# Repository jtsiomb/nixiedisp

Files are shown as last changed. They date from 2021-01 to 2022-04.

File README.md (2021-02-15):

nixiedisp - USB nixie tube display
==================================

nixiedisp

Nixiedisp is a 6-digit nixie tube numeric display, software-controlled over USB
or RS232, that also functions standalone as a clock.

Features:
  - Controlled over USB or RS232 serial port to display arbitrary numbers, set
    the time/date, change settings, and switch between modes of operation.
  - Standalone operation as a clock or stopwatch timer with a battery-backed
    real-time clock (CR2032 coin cell).
  - Designed to use soviet IN-14 nixie tubes.
  - Powered by a 12v DC supply through a standard 2mm barrel jack (center-positive).

Excercise caution when operating without an enclosure, there are high voltages
(180V DC) present in the power supply section of the board, and around the
nixie tubes.

Project website: http://nuclear.mutantstargoat.com/hw/nixiedisp  
Github repo: https://github.com/jtsiomb/nixiedisp  

Project structure:

 - `hw/`: hardware design
 - `fw/`: firmware for the on-board AVR microcontroller
 - `sw/`: end-user host-side software for controlling the device from a computer

License
-------
Copyright (C) 2020-2021 John Tsiombikas <nuclear@member.fsf.org>

Hardware designs and software (firmware) in this project are free. Feel free to
use, modify, and/or redistribute under the terms of the GNU General Public
License v3, or at your option any later version published by the Free Software
Foundation. See COPYING for details.

How to build a nixiedisp device
-------------------------------
To build one of these for yourself, you need to:

  1. Zip up the contents of the `hw/gerber` directory, and send them to a PCB
     manufacturer to get boards made. For my own boards I used `jlcpcb.com`.

  2. Order the components listed in the bill of materials (`hw/bom.ods`). I
     ordered mine from `mouser.com`, and the spreadsheet contains the mouser
     reference number for each component, to make it easy to order the whole lot
     without too much searching. Make sure to order at least as many of each one
     of them, as specified in the bom.

  3. Find 6 (optionally 4) soviet IN-14 nixie tubes. They tend to go for about
     $10 - $15 each on ebay.

  4. Find a 12v DC power supply with a barrel jack (2mm center pin),
     center-positive (`+ -o)- -`), to power the board. It doesn't have to be
     regulated, but it must be able to provide about 500mA at 12v.
     Typical power consumption is 2-3W.

  5. If you got the git version of this project, you'll need to build the
     firmware by changing into `fw` and typing `make`. You'll need to have
     `avr-gcc`, `libc-avr`, and GNU make installed for this. Release archives
     include a pre-built firmware image you can use (`fw/nixiedisp.hex`).

  6. Assemble the board, and program the microcontroller with a suitable AVR
     ISP. If you have `avrdude` installed, you can simply change into `fw` and
     type `make program`, with the board powered up and the programmer
     connected.

If you don't need the serial port (RS232) option, you can leave J1 (the DB9
connector), U2 (max232 level converter) and all its surrounding electrolytic
capacitors (C1, C2, C4, C8 and C15) unpopulated, and install a 10k pull-up
resistor across the pads of J7 (usbpwr).

References
----------
High-voltage power supply based on Michael Moorrees' nixie supply MK1.5:
https://threeneurons.wordpress.com/nixie-power-supply

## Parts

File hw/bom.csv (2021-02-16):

Reference | Quantity | Description | Footprint | Mouser ID | Unit price | Cost
BT1 | 1 | CR2032 battery holder | SMD battery holder Keystone 1060 | 534-1060TR | 1.380 € | 1.380 €
C3 C5 C6 C7 C9 C10 C13 C14 C17 C18 C21 C24 C27 C30 C33 | 15 | 0.1uF | SMD 0805 | 581-08055C104K | 0.034 € | 0.510 €
C11 C12 | 2 | 22pF | SMD 0805 | 80-C0805C220K1HACTU | 0.032 € | 0.064 €
C16 | 1 | 2.2nF | SMD 0805 | 187-CL21B222JBANNNC | 0.020 € | 0.020 €
C1 C2 C4 C8 C15 | 5 | 1uF electrolytic (RS232 option) | SMD electrolytic 4x5.4 | 710-865060640001 | 0.136 € | 0.680 €
C35 C36 | 2 | 0.33uF electrolytic | SMD electrolytic 4x5.4 | 710-865230640003 | 0.152 € | 0.304 €
C37 | 1 | 220uF low-ESR electrolytic | SMD electrolytic 8x10 | 667-EEE-FP1V221AL | 0.526 € | 0.526 €
C38 | 1 | 10nF | SMD 0805 | 187-CL21B103JBANNNC | 0.020 € | 0.020 €
C39 | 1 | 2.2uF 250V | Through-hole radial electrolytic | 647-UVR2E2R2MED1TD | 0.220 € | 0.220 €
D1 | 1 | 1N4148 | SMD SOD-323 (0805) | 750-1N4148WS-HF | 0.106 € | 0.106 €
D2 | 1 | MUR160 | SMD DO-214A (SMB) | 821-MUR160SR5G | 0.250 € | 0.250 €
J1 | 1 | DB9 male (RS232 option) | Through-hole DB9 male | 523-L717SDE09P1ACH | 1.350 € | 1.350 €
J2 | 1 | Micro-USB connector | USB Micro-B Molex-105017-0001 | 538-105017-0001 | 0.703 € | 0.703 €
J3 | 1 | AVR programming header | 2x3 male pin header 2.54mm pitch | 710-61200621621 | 0.381 € | 0.381 €
J4 | 1 | DC barrel jack | barrel jack 2mm center pin | 490-PJ-202A | 0.500 € | 0.500 €
J5 | 1 | Hour-separator LED connector | 1x3 female socket 2.54mm pitch | 538-90147-1103 | 0.930 € | 0.930 €
J6 | 1 | pwr sw | 1x2 male pin header 2.54mm pitch | 538-22-28-4112 | 0.398 € | 0.398 €
L1 | 1 | 220uH | SMD inductor 14x18.3 | 652-SDR1806-221KL | 0.813 € | 0.813 €
Q1 Q2 | 2 | MMBTA55 PNP transistor | SMD SOT-23 | 863-MMBTA55LT1G | 0.152 € | 0.304 €
Q3-Q68 | 66 | MMBTA42 NPN transistor | SMD SOT-23 | 863-MMBTA42LT1G | 0.054 € | 3.564 €
Q69 | 1 | IRF740A | SMD TO-263-3 | 844-IRF740ASPBF | 1.700 € | 1.700 €
R1 R2 R27 | 4 | 10k | SMD 0805 | 71-CRCW080510K0JNEAC | 0.033 € | 0.132 €
R15-R20 R22-R26 R28-R33 R35-R39 R41-R46 R48-R52 R54-R59 R61-R65 R67-R72 R74-R78 R80-R85 R87-R91 | 66 | 47k | SMD 0805 | 652-CR0805FX-4702ELF | 0.007 € | 0.462 €
R21 R34 R47 R60 R73 R86 | 6 | 160k | SMD 0805 | 660-RK73H2ATTD1603F | 0.013 € | 0.078 €
R3 R4 R7 | 3 | 1 ohm | SMD 0805 | 603-RC0805FR-071RL | 0.044 € | 0.132 €
R5 R6 R8 | 2 | 1k | SMD 0805 | 71-CRCW08051K00JNEAC | 0.033 € | 0.066 €
R9 R10 R11 R12 R13 R14 | 6 | 24k | SMD 0805 | 660-RK73H2ATTD2402F | 0.014 € | 0.084 €
R93 | 1 | 475k | SMD 0805 | 667-ERJ-6ENF4753V | 0.055 € | 0.055 €
R94 | 1 | 3.32k | SMD 0805 | 71-CRCW0805-3.32K-E3 | 0.048 € | 0.048 €
SW1-SW3 | 1 | Right-angle tactile button | SMD right-angle | 113-TA34W2VTR | 1.360 € | 1.360 €
U1 | 1 | Atmega328PB-AU | TQFP-32 | 556-ATMEGA328PB-AU | 1.130 € | 1.130 €
U14 U15 U16 U17 U18 U19 | 6 | 74HC4514 | SOIC-24 wide | 771-74HC4514D-T | 0.864 € | 5.184 €
U2 | 1 | MAX232 (RS232 option) | SOIC-16 | 595-MAX232DR | 0.737 € | 0.737 €
U3 | 1 | 74HC126 | SOIC-14 | 595-SN74HC126DR | 0.237 € | 0.237 €
U32 | 1 | DS1302Z+ | SOIC-8 | 700-DS1302ZT&R | 2.790 € | 2.790 €
U33 | 1 | MC34063AD | SOIC-8 | 595-MC34063ADR | 0.296 € | 0.296 €
U34 | 1 | 7805 | SMD TO-252-2 DPAK | 863-MC7805CDTRKG | 0.356 € | 0.356 €
U4 | 1 | MCP2221AxSL | SOIC-14 | 579-MCP2221A-I/SL | 1.680 € | 1.680 €
U5 U6 U7 | 3 | 74HC164 | SOIC-14 | 771-74HC164D-T | 0.220 € | 0.660 €
U8 U9 U10 U11 U12 U13 | 6 | IN14 | Nixie tube IN-14 |  |  | 0.000 €
Y1 | 1 | 14.7456MHz | SMD crystal ECS CSM3X 2pin 7.6x4.1mm | 815-ABLS7M-14.745B2T | 0.288 € | 0.288 €
Y2 | 1 | 32.768KHz | SMD crystal 2-pin 2x1.2mm (alt.footprint Y3) | 815-ABS0632768KHZ61T |  | 0.000 €
Y3 | 1 | 32.768KHz | Through-hole crystal 3x8mm (alt.footprint Y2) | 695-CFS-20632768EZBB | 0.347 € | 0.347 €
 | 2 | Amber 3mm LED (hour sep.) | Through-hole 3mm LED | 859-LTL-1CHA | 0.144 € | 0.288 €
 |  |  |  |  | Total cost: | 31.133 €

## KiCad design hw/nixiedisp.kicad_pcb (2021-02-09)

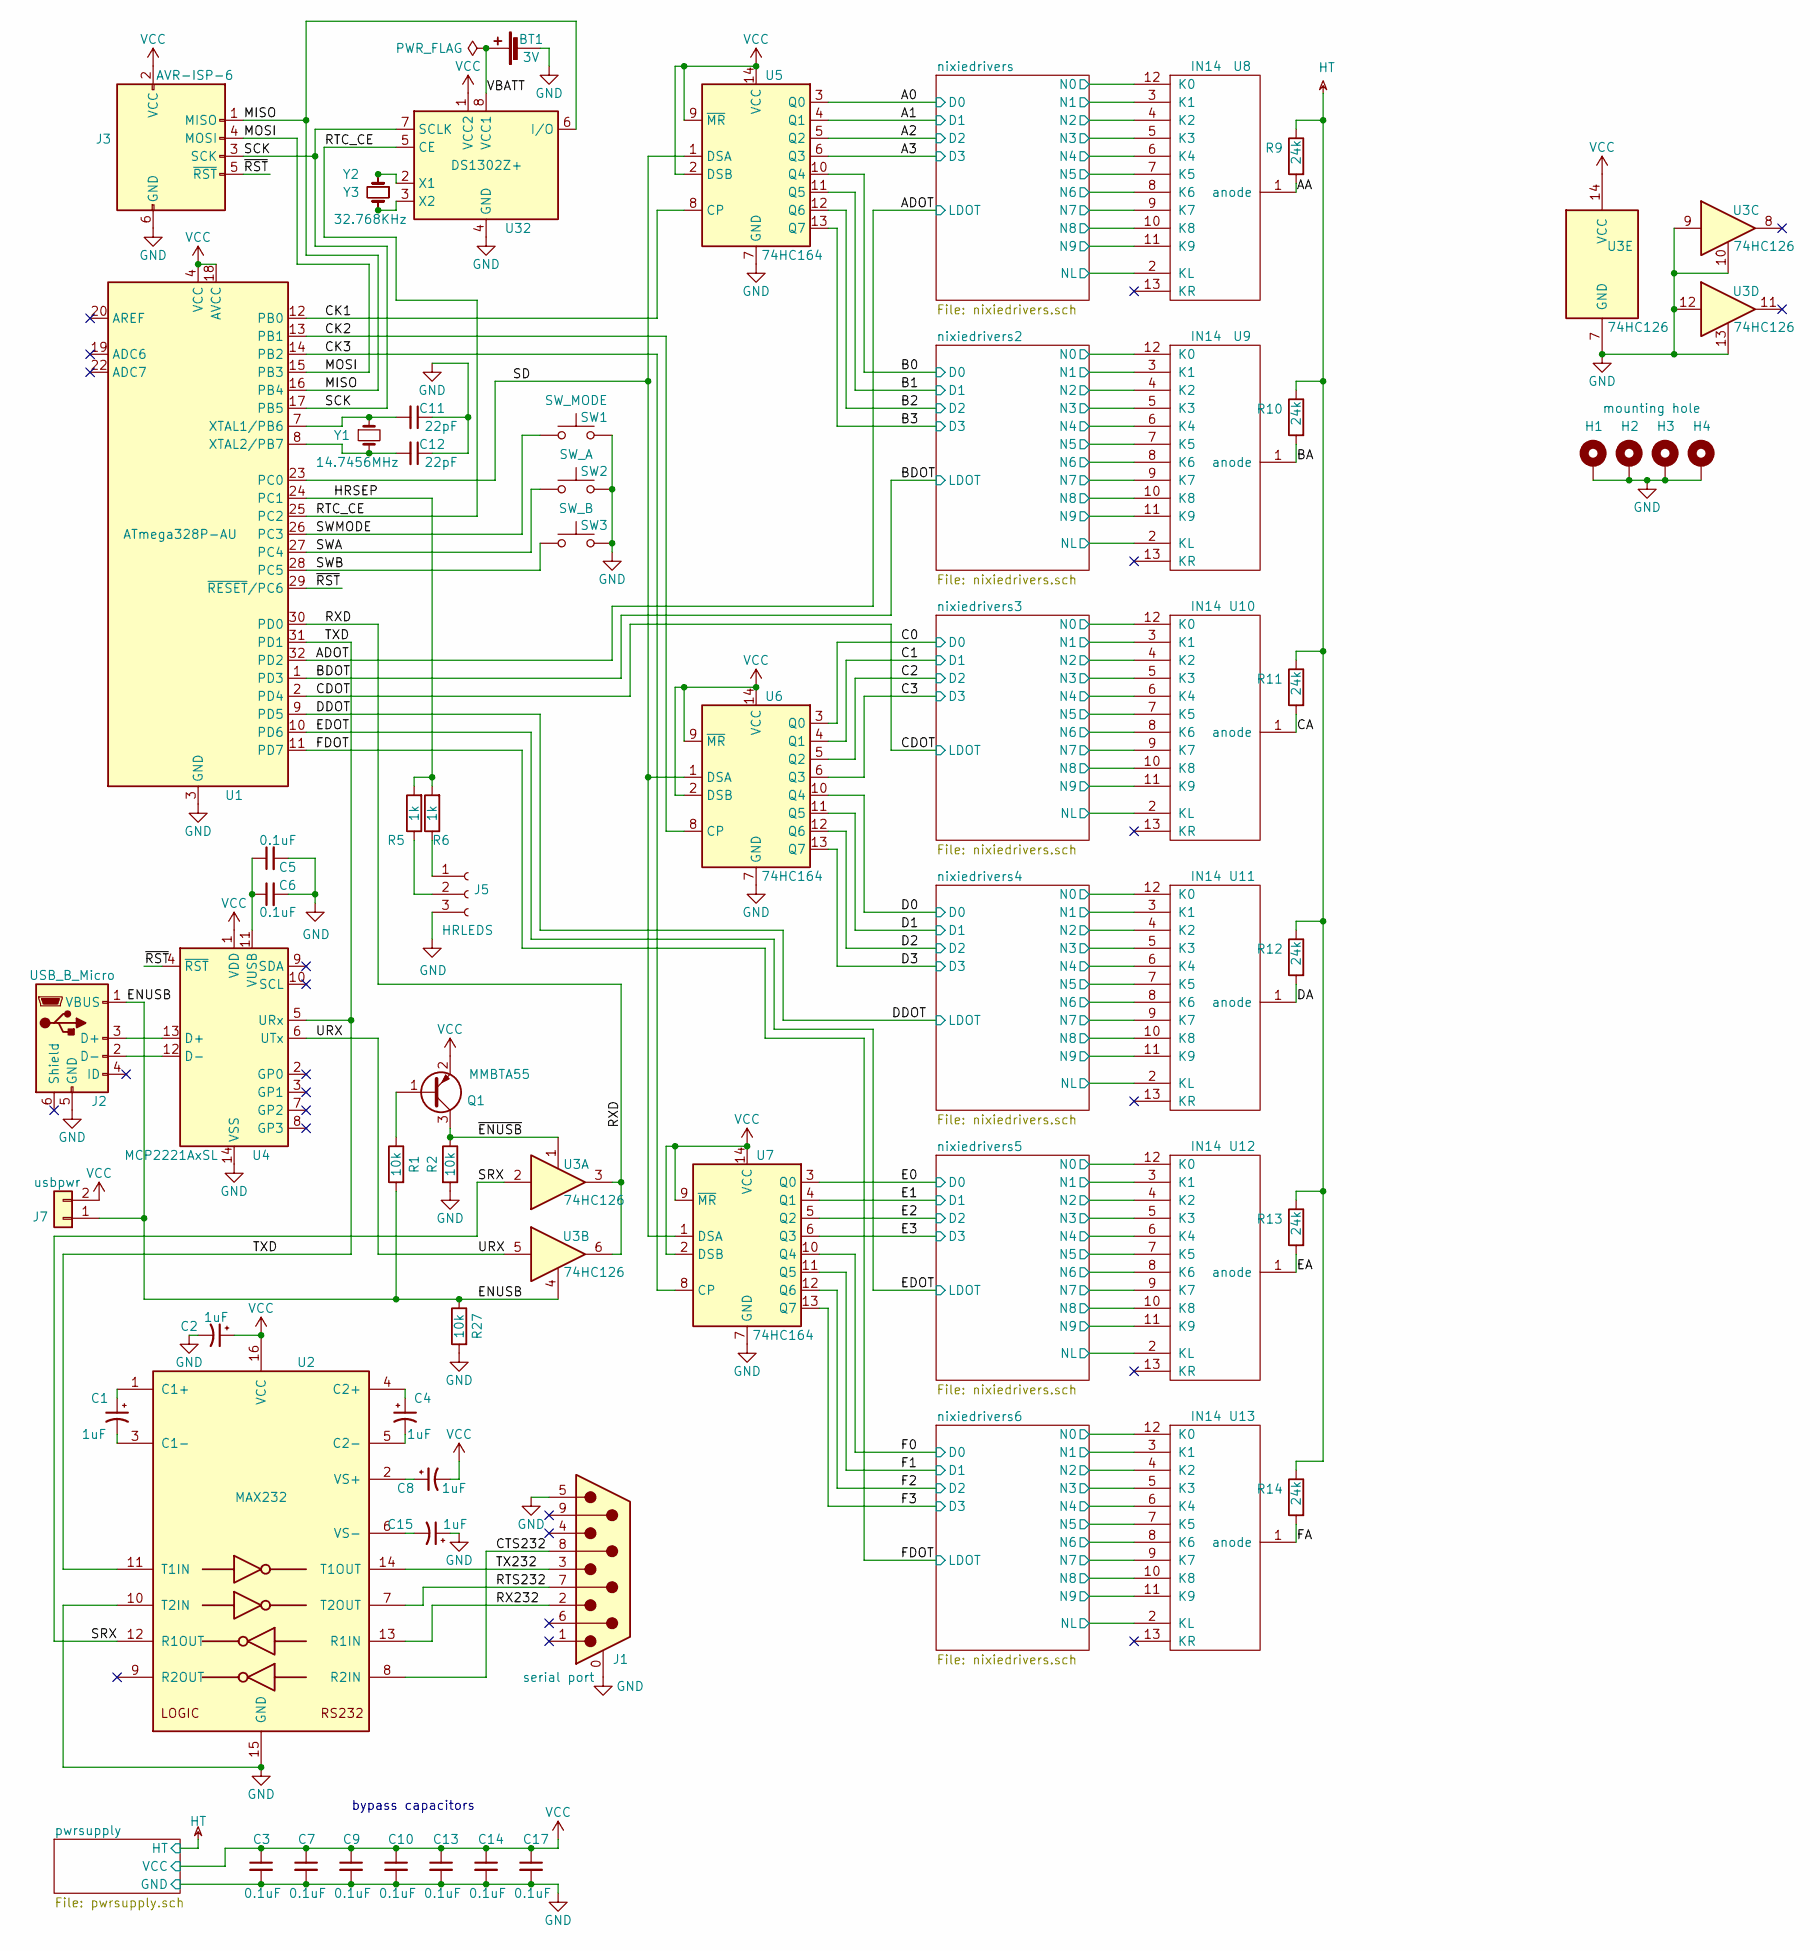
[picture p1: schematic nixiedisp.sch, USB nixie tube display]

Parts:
BT1: 3V; BatteryHolder_Keystone_1060_1x2032
C1, C2, C4, C8, C15: 1uF; CP_Elec_4x3.9
C3, C5, C6, C7, C9, C10, C13, C14, C17: 0.1uF; C_0805_2012Metric_Pad1.15x1.40mm_HandSolder
C11, C12: 22pF; C_0805_2012Metric_Pad1.15x1.40mm_HandSolder
H1, H2, H3, H4: mounting hole; MountingHole_3.2mm_M3_Pad_Via
J1: serial port; DSUB-9_Male_Horizontal_P2.77x2.84mm_EdgePinOffset7.70mm_Hou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
J2: USB_B_Micro; USB_Micro-B_Molex-105017-0001
J3: AVR-ISP-6; IDC-Header_2x03_P2.54mm_Vertical
J5: HRLEDS; PinSocket_1x03_P2.54mm_Vertical
J7: usbpwr; PinHeader_1x02_P2.54mm_Vertical
Q1: MMBTA55; SOT-23
R1, R2, R27: 10k; R_0805_2012Metric_Pad1.15x1.40mm_HandSolder
R5, R6: 1k; R_0805_2012Metric_Pad1.15x1.40mm_HandSolder
R9, R10, R11, R12, R13, R14: 24k; R_0805_2012Metric_Pad1.15x1.40mm_HandSolder
SW1: SW_MODE; switch
SW2: SW_A; switch
SW3: SW_B; switch
U1: ATmega328P-AU; TQFP-32_7x7mm_P0.8mm
U2: MAX232; SOIC-16_3.9x9.9mm_P1.27mm
U3: 74HC126; SOIC-14_3.9x8.7mm_P1.27mm
U4: MCP2221AxSL; SOIC-14_3.9x8.7mm_P1.27mm
U5, U6, U7: 74HC164; SOIC-14_3.9x8.7mm_P1.27mm
U8, U9, U10, U11, U12, U13: IN14; nixie_in14
U32: DS1302Z+; SOIC-8_3.9x4.9mm_P1.27mm
Y1: 14.7456MHz; Crystal_SMD_ECS_CSM3X-2Pin_7.6x4.1mm
Y2: 32.768KHz; Crystal_SMD_2012-2Pin_2.0x1.2mm_HandSoldering
Y3: 32.768KHz; Crystal_C38-LF_D3.0mm_L8.0mm_Horizontal

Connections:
/A0: U5.3 (Q0); also elsewhere on the board
/A1: U5.4 (Q1); also elsewhere on the board
/A2: U5.5 (Q2); also elsewhere on the board
/A3: U5.6 (Q3); also elsewhere on the board
/AA: R9.2, U8.1 (anode)
/ADOT: U1.32 (PD2); also elsewhere on the board
/B0: U5.10 (Q4); also elsewhere on the board
/B1: U5.11 (Q5); also elsewhere on the board
/B2: U5.12 (Q6); also elsewhere on the board
/B3: U5.13 (Q7); also elsewhere on the board
/BA: R10.2, U9.1 (anode)
/BDOT: U1.1 (PD3); also elsewhere on the board
/C0: U6.3 (Q0); also elsewhere on the board
/C1: U6.4 (Q1); also elsewhere on the board
/C2: U6.5 (Q2); also elsewhere on the board
/C3: U6.6 (Q3); also elsewhere on the board
/CA: R11.2, U10.1 (anode)
/CDOT: U1.2 (PD4); also elsewhere on the board
/CK1: U1.12 (PB0), U5.8 (CP)
/CK2: U1.13 (PB1), U6.8 (CP)
/CK3: U1.14 (PB2), U7.8 (CP)
/CTS232: J1.8, U2.8 (R2IN)
/D0: U6.10 (Q4); also elsewhere on the board
/D1: U6.11 (Q5); also elsewhere on the board
/D2: U6.12 (Q6); also elsewhere on the board
/D3: U6.13 (Q7); also elsewhere on the board
/DA: R12.2, U11.1 (anode)
/DDOT: U1.9 (PD5); also elsewhere on the board
/E0: U7.3 (Q0); also elsewhere on the board
/E1: U7.4 (Q1); also elsewhere on the board
/E2: U7.5 (Q2); also elsewhere on the board
/E3: U7.6 (Q3); also elsewhere on the board
/EA: R13.2, U12.1 (anode)
/EDOT: U1.10 (PD6); also elsewhere on the board
/ENUSB: J2.1 (VBUS), J7.1, R1.2, R27.1, U3.4
/F0: U7.10 (Q4); also elsewhere on the board
/F1: U7.11 (Q5); also elsewhere on the board
/F2: U7.12 (Q6); also elsewhere on the board
/F3: U7.13 (Q7); also elsewhere on the board
/FA: R14.2, U13.1 (anode)
/FDOT: U1.11 (PD7); also elsewhere on the board
/HRSEP: R5.2, R6.2, U1.24 (PC1)
/MISO: J3.1 (MISO), U1.16 (PB4), U32.6 (I/O)
/MOSI: J3.4 (MOSI), U1.15 (PB3)
/RTC_CE: U1.25 (PC2), U32.5 (CE)
/RTS232: J1.7, U2.7 (T2OUT)
/RX232: J1.2, U2.13 (R1IN)
/RXD: U1.30 (PD0), U3.3, U3.6
/SCK: J3.3 (SCK), U1.17 (PB5), U32.7 (SCLK)
/SD: U1.23 (PC0), U5.1 (DSA), U6.1 (DSA), U7.1 (DSA)
/SRX: U2.12 (R1OUT), U3.2
/SWA: SW2.1, U1.27 (PC4)
/SWB: SW3.1, U1.28 (PC5)
/SWMODE: SW1.1, U1.26 (PC3)
/TX232: J1.3, U2.14 (T1OUT)
/TXD: U1.31 (PD1), U2.11 (T1IN), U4.5 (URx)
/URX: U3.5, U4.6 (UTx)
/VBATT: BT1.1 (+), U32.8 (VCC1)
/nixiedrivers2/N0: U9.12 (K0); also elsewhere on the board
/nixiedrivers2/N1: U9.3 (K1); also elsewhere on the board
/nixiedrivers2/N2: U9.4 (K2); also elsewhere on the board
/nixiedrivers2/N3: U9.5 (K3); also elsewhere on the board
/nixiedrivers2/N4: U9.6 (K4); also elsewhere on the board
/nixiedrivers2/N5: U9.7 (K5); also elsewhere on the board
/nixiedrivers2/N6: U9.8 (K6); also elsewhere on the board
/nixiedrivers2/N7: U9.9 (K7); also elsewhere on the board
/nixiedrivers2/N8: U9.10 (K8); also elsewhere on the board
/nixiedrivers2/N9: U9.11 (K9); also elsewhere on the board
/nixiedrivers2/NL: U9.2 (KL); also elsewhere on the board
/nixiedrivers3/N0: U10.12 (K0); also elsewhere on the board
/nixiedrivers3/N1: U10.3 (K1); also elsewhere on the board
/nixiedrivers3/N2: U10.4 (K2); also elsewhere on the board
/nixiedrivers3/N3: U10.5 (K3); also elsewhere on the board
/nixiedrivers3/N4: U10.6 (K4); also elsewhere on the board
/nixiedrivers3/N5: U10.7 (K5); also elsewhere on the board
/nixiedrivers3/N6: U10.8 (K6); also elsewhere on the board
/nixiedrivers3/N7: U10.9 (K7); also elsewhere on the board
/nixiedrivers3/N8: U10.10 (K8); also elsewhere on the board
/nixiedrivers3/N9: U10.11 (K9); also elsewhere on the board
/nixiedrivers3/NL: U10.2 (KL); also elsewhere on the board
/nixiedrivers4/N0: U11.12 (K0); also elsewhere on the board
/nixiedrivers4/N1: U11.3 (K1); also elsewhere on the board
/nixiedrivers4/N2: U11.4 (K2); also elsewhere on the board
/nixiedrivers4/N3: U11.5 (K3); also elsewhere on the board
/nixiedrivers4/N4: U11.6 (K4); also elsewhere on the board
/nixiedrivers4/N5: U11.7 (K5); also elsewhere on the board
/nixiedrivers4/N6: U11.8 (K6); also elsewhere on the board
/nixiedrivers4/N7: U11.9 (K7); also elsewhere on the board
/nixiedrivers4/N8: U11.10 (K8); also elsewhere on the board
/nixiedrivers4/N9: U11.11 (K9); also elsewhere on the board
/nixiedrivers4/NL: U11.2 (KL); also elsewhere on the board
/nixiedrivers5/N0: U12.12 (K0); also elsewhere on the board
/nixiedrivers5/N1: U12.3 (K1); also elsewhere on the board
/nixiedrivers5/N2: U12.4 (K2); also elsewhere on the board
/nixiedrivers5/N3: U12.5 (K3); also elsewhere on the board
/nixiedrivers5/N4: U12.6 (K4); also elsewhere on the board
/nixiedrivers5/N5: U12.7 (K5); also elsewhere on the board
/nixiedrivers5/N6: U12.8 (K6); also elsewhere on the board
/nixiedrivers5/N7: U12.9 (K7); also elsewhere on the board
/nixiedrivers5/N8: U12.10 (K8); also elsewhere on the board
/nixiedrivers5/N9: U12.11 (K9); also elsewhere on the board
/nixiedrivers5/NL: U12.2 (KL); also elsewhere on the board
/nixiedrivers6/N0: U13.12 (K0); also elsewhere on the board
/nixiedrivers6/N1: U13.3 (K1); also elsewhere on the board
/nixiedrivers6/N2: U13.4 (K2); also elsewhere on the board
/nixiedrivers6/N3: U13.5 (K3); also elsewhere on the board
/nixiedrivers6/N4: U13.6 (K4); also elsewhere on the board
/nixiedrivers6/N5: U13.7 (K5); also elsewhere on the board
/nixiedrivers6/N6: U13.8 (K6); also elsewhere on the board
/nixiedrivers6/N7: U13.9 (K7); also elsewhere on the board
/nixiedrivers6/N8: U13.10 (K8); also elsewhere on the board
/nixiedrivers6/N9: U13.11 (K9); also elsewhere on the board
/nixiedrivers6/NL: U13.2 (KL); also elsewhere on the board
/nixiedrivers/N0: U8.12 (K0); also elsewhere on the board
/nixiedrivers/N1: U8.3 (K1); also elsewhere on the board
/nixiedrivers/N2: U8.4 (K2); also elsewhere on the board
/nixiedrivers/N3: U8.5 (K3); also elsewhere on the board
/nixiedrivers/N4: U8.6 (K4); also elsewhere on the board
/nixiedrivers/N5: U8.7 (K5); also elsewhere on the board
/nixiedrivers/N6: U8.8 (K6); also elsewhere on the board
/nixiedrivers/N7: U8.9 (K7); also elsewhere on the board
/nixiedrivers/N8: U8.10 (K8); also elsewhere on the board
/nixiedrivers/N9: U8.11 (K9); also elsewhere on the board
/nixiedrivers/NL: U8.2 (KL); also elsewhere on the board
/~ENUSB: Q1.3 (C), R2.1, U3.1
/~RST: J3.5 (~RST), U1.29 (~RESET~/PC6), U4.4 (~RST)
GND: BT1.2 (-), C2.2, C3.2, C5.2, C6.2, C7.2, C9.2, C10.2, C11.1, C12.1, C13.2, C14.2, C15.1, C17.2, H1.1, H2.1, H3.1, H4.1, J1.0 (PAD), J1.5, J2.5 (GND), J3.6 (GND), J5.3, R2.2, R27.2, SW1.2, SW2.2, SW3.2, U1.3 (GND), U1.5 (GND), U1.21 (GND), U2.10 (T2IN), U2.15 (GND), U3.7 (GND), U3.9, U3.10, U3.12, U3.13, U4.14 (VSS), U5.7 (GND), U6.7 (GND), U7.7 (GND), U32.4 (GND); also elsewhere on the board
HT: R9.1, R10.1, R11.1, R12.1, R13.1, R14.1; also elsewhere on the board
unnamed: C1.1, U2.1 (C1+)
unnamed: C1.2, U2.3 (C1-)
unnamed: C4.1, U2.4 (C2+)
unnamed: C4.2, U2.5 (C2-)
unnamed: C5.1, C6.1, U4.11 (VUSB)
unnamed: C8.1, U2.2 (VS+)
unnamed: C11.2, U1.7 (XTAL1/PB6), Y1.1
unnamed: C12.2, U1.8 (XTAL2/PB7), Y1.2
unnamed: C15.2, U2.6 (VS-)
unnamed: J2.2 (D-), U4.12 (D-)
unnamed: J2.3 (D+), U4.13 (D+)
unnamed: J5.1, R6.1
unnamed: J5.2, R5.1
unnamed: Q1.1 (B), R1.1
unnamed: U32.2 (X1), Y2.1, Y3.1
unnamed: U32.3 (X2), Y2.2, Y3.2
VCC: C2.1, C3.1, C7.1, C8.2, C9.1, C10.1, C13.1, C14.1, C17.1, J3.2 (VCC), J7.2, Q1.2 (E), U1.4 (VCC), U1.6 (VCC), U1.18 (AVCC), U2.16 (VCC), U3.14 (VCC), U4.1 (VDD), U5.2 (DSB), U5.9 (~MR), U5.14 (VCC), U6.2 (DSB), U6.9 (~MR), U6.14 (VCC), U7.2 (DSB), U7.9 (~MR), U7.14 (VCC), U32.1 (VCC2); also elsewhere on the board

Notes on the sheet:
bypass capacitors

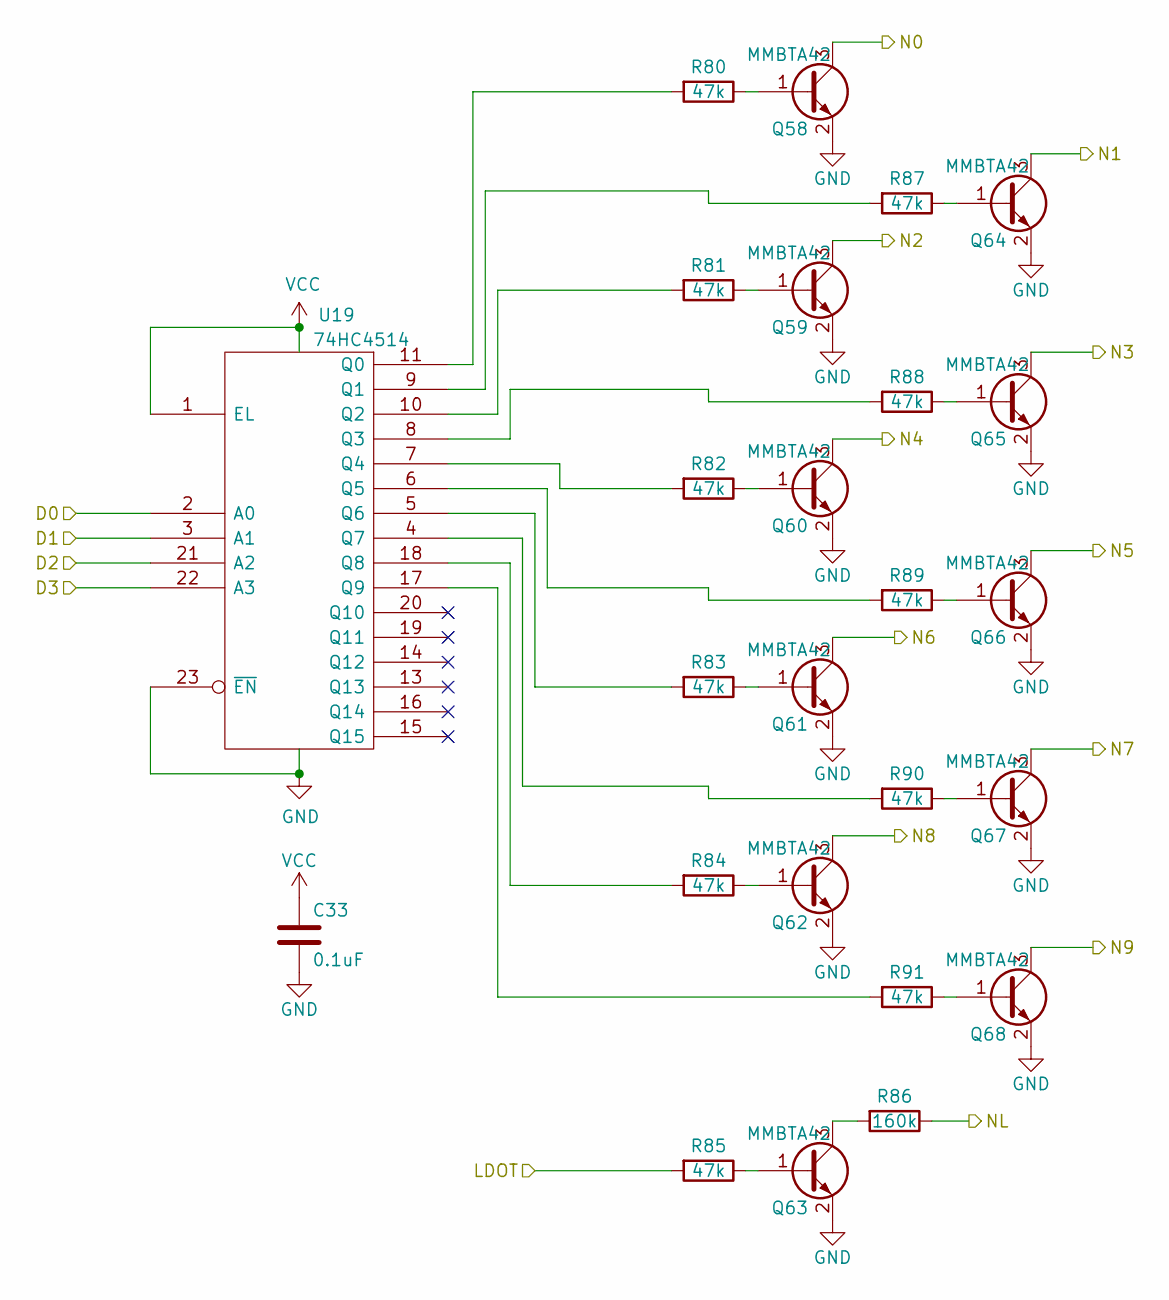
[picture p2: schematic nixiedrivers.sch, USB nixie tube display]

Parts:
C18: 0.1uF; C_0805_2012Metric_Pad1.15x1.40mm_HandSolder
Q3, Q4, Q5, Q6, Q7, Q8, Q9, Q10, Q11, Q12, Q13: MMBTA42; SOT-23
R15, R16, R17, R18, R19, R20, R22, R23, R24, R25, R26: 47k; R_0805_2012Metric_Pad1.15x1.40mm_HandSolder
R21: 160k; R_0805_2012Metric_Pad1.15x1.40mm_HandSolder
U14: 74HC4514; SOIC-24W_7.5x15.4mm_P1.27mm

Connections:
/A0: U14.2 (A0); also elsewhere on the board
/A1: U14.3 (A1); also elsewhere on the board
/A2: U14.21 (A2); also elsewhere on the board
/A3: U14.22 (A3); also elsewhere on the board
/ADOT: R20.2; also elsewhere on the board
/nixiedrivers/N0: Q3.3 (C); also elsewhere on the board
/nixiedrivers/N1: Q9.3 (C); also elsewhere on the board
/nixiedrivers/N2: Q4.3 (C); also elsewhere on the board
/nixiedrivers/N3: Q10.3 (C); also elsewhere on the board
/nixiedrivers/N4: Q5.3 (C); also elsewhere on the board
/nixiedrivers/N5: Q11.3 (C); also elsewhere on the board
/nixiedrivers/N6: Q6.3 (C); also elsewhere on the board
/nixiedrivers/N7: Q12.3 (C); also elsewhere on the board
/nixiedrivers/N8: Q7.3 (C); also elsewhere on the board
/nixiedrivers/N9: Q13.3 (C); also elsewhere on the board
/nixiedrivers/NL: R21.1; also elsewhere on the board
GND: C18.2, Q3.2 (E), Q4.2 (E), Q5.2 (E), Q6.2 (E), Q7.2 (E), Q8.2 (E), Q9.2 (E), Q10.2 (E), Q11.2 (E), Q12.2 (E), Q13.2 (E), U14.12 (Vss), U14.23 (~EN); also elsewhere on the board
unnamed: Q3.1 (B), R15.1
unnamed: Q4.1 (B), R16.1
unnamed: Q5.1 (B), R17.1
unnamed: Q6.1 (B), R18.1
unnamed: Q7.1 (B), R19.1
unnamed: Q8.1 (B), R20.1
unnamed: Q8.3 (C), R21.2
unnamed: Q9.1 (B), R22.1
unnamed: Q10.1 (B), R23.1
unnamed: Q11.1 (B), R24.1
unnamed: Q12.1 (B), R25.1
unnamed: Q13.1 (B), R26.1
unnamed: R15.2, U14.11 (Q0)
unnamed: R16.2, U14.10 (Q2)
unnamed: R17.2, U14.7 (Q4)
unnamed: R18.2, U14.5 (Q6)
unnamed: R19.2, U14.18 (Q8)
unnamed: R22.2, U14.9 (Q1)
unnamed: R23.2, U14.8 (Q3)
unnamed: R24.2, U14.6 (Q5)
unnamed: R25.2, U14.4 (Q7)
unnamed: R26.2, U14.17 (Q9)
VCC: C18.1, U14.1 (EL), U14.24 (Vdd); also elsewhere on the board

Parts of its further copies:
C21, C24, C27, C30, C33: 0.1uF; C_0805_2012Metric_Pad1.15x1.40mm_HandSolder
Q14, Q15, Q16, Q17, Q18, Q19, Q20, Q21, Q22, Q23, Q24, Q25, Q26, Q27, Q28, Q29, Q30, Q31, Q32, Q33, Q34, Q35, Q36, Q37, Q38, Q39, Q40, Q41, Q42, Q43, Q44, Q45, Q46, Q47, Q48, Q49, Q50, Q51, Q52, Q53, Q54, Q55, Q56, Q57, Q58, Q59, Q60, Q61, Q62, Q63, Q64, Q65, Q66, Q67, Q68: MMBTA42; SOT-23
R28, R29, R30, R31, R32, R33, R35, R36, R37, R38, R39, R41, R42, R43, R44, R45, R46, R48, R49, R50, R51, R52, R54, R55, R56, R57, R58, R59, R61, R62, R63, R64, R65, R67, R68, R69, R70, R71, R72, R74, R75, R76, R77, R78, R80, R81, R82, R83, R84, R85, R87, R88, R89, R90, R91: 47k; R_0805_2012Metric_Pad1.15x1.40mm_HandSolder
R34, R47, R60, R73, R86: 160k; R_0805_2012Metric_Pad1.15x1.40mm_HandSolder
U15, U16, U17, U18, U19: 74HC4514; SOIC-24W_7.5x15.4mm_P1.27mm

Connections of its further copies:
/B0: U15.2 (A0); also elsewhere on the board
/B1: U15.3 (A1); also elsewhere on the board
/B2: U15.21 (A2); also elsewhere on the board
/B3: U15.22 (A3); also elsewhere on the board
/BDOT: R33.2; also elsewhere on the board
/C0: U16.2 (A0); also elsewhere on the board
/C1: U16.3 (A1); also elsewhere on the board
/C2: U16.21 (A2); also elsewhere on the board
/C3: U16.22 (A3); also elsewhere on the board
/CDOT: R46.2; also elsewhere on the board
/D0: U19.2 (A0); also elsewhere on the board
/D1: U19.3 (A1); also elsewhere on the board
/D2: U19.21 (A2); also elsewhere on the board
/D3: U19.22 (A3); also elsewhere on the board
/DDOT: R85.2; also elsewhere on the board
/E0: U17.2 (A0); also elsewhere on the board
/E1: U17.3 (A1); also elsewhere on the board
/E2: U17.21 (A2); also elsewhere on the board
/E3: U17.22 (A3); also elsewhere on the board
/EDOT: R59.2; also elsewhere on the board
/F0: U18.2 (A0); also elsewhere on the board
/F1: U18.3 (A1); also elsewhere on the board
/F2: U18.21 (A2); also elsewhere on the board
/F3: U18.22 (A3); also elsewhere on the board
/FDOT: R72.2; also elsewhere on the board
/nixiedrivers2/N0: Q14.3 (C); also elsewhere on the board
/nixiedrivers2/N1: Q20.3 (C); also elsewhere on the board
/nixiedrivers2/N2: Q15.3 (C); also elsewhere on the board
/nixiedrivers2/N3: Q21.3 (C); also elsewhere on the board
/nixiedrivers2/N4: Q16.3 (C); also elsewhere on the board
/nixiedrivers2/N5: Q22.3 (C); also elsewhere on the board
/nixiedrivers2/N6: Q17.3 (C); also elsewhere on the board
/nixiedrivers2/N7: Q23.3 (C); also elsewhere on the board
/nixiedrivers2/N8: Q18.3 (C); also elsewhere on the board
/nixiedrivers2/N9: Q24.3 (C); also elsewhere on the board
/nixiedrivers2/NL: R34.1; also elsewhere on the board
/nixiedrivers3/N0: Q25.3 (C); also elsewhere on the board
/nixiedrivers3/N1: Q31.3 (C); also elsewhere on the board
/nixiedrivers3/N2: Q26.3 (C); also elsewhere on the board
/nixiedrivers3/N3: Q32.3 (C); also elsewhere on the board
/nixiedrivers3/N4: Q27.3 (C); also elsewhere on the board
/nixiedrivers3/N5: Q33.3 (C); also elsewhere on the board
/nixiedrivers3/N6: Q28.3 (C); also elsewhere on the board
/nixiedrivers3/N7: Q34.3 (C); also elsewhere on the board
/nixiedrivers3/N8: Q29.3 (C); also elsewhere on the board
/nixiedrivers3/N9: Q35.3 (C); also elsewhere on the board
/nixiedrivers3/NL: R47.1; also elsewhere on the board
/nixiedrivers4/N0: Q58.3 (C); also elsewhere on the board
/nixiedrivers4/N1: Q64.3 (C); also elsewhere on the board
/nixiedrivers4/N2: Q59.3 (C); also elsewhere on the board
/nixiedrivers4/N3: Q65.3 (C); also elsewhere on the board
/nixiedrivers4/N4: Q60.3 (C); also elsewhere on the board
/nixiedrivers4/N5: Q66.3 (C); also elsewhere on the board
/nixiedrivers4/N6: Q61.3 (C); also elsewhere on the board
/nixiedrivers4/N7: Q67.3 (C); also elsewhere on the board
/nixiedrivers4/N8: Q62.3 (C); also elsewhere on the board
/nixiedrivers4/N9: Q68.3 (C); also elsewhere on the board
/nixiedrivers4/NL: R86.1; also elsewhere on the board
/nixiedrivers5/N0: Q36.3 (C); also elsewhere on the board
/nixiedrivers5/N1: Q42.3 (C); also elsewhere on the board
/nixiedrivers5/N2: Q37.3 (C); also elsewhere on the board
/nixiedrivers5/N3: Q43.3 (C); also elsewhere on the board
/nixiedrivers5/N4: Q38.3 (C); also elsewhere on the board
/nixiedrivers5/N5: Q44.3 (C); also elsewhere on the board
/nixiedrivers5/N6: Q39.3 (C); also elsewhere on the board
/nixiedrivers5/N7: Q45.3 (C); also elsewhere on the board
/nixiedrivers5/N8: Q40.3 (C); also elsewhere on the board
/nixiedrivers5/N9: Q46.3 (C); also elsewhere on the board
/nixiedrivers5/NL: R60.1; also elsewhere on the board
/nixiedrivers6/N0: Q47.3 (C); also elsewhere on the board
/nixiedrivers6/N1: Q53.3 (C); also elsewhere on the board
/nixiedrivers6/N2: Q48.3 (C); also elsewhere on the board
/nixiedrivers6/N3: Q54.3 (C); also elsewhere on the board
/nixiedrivers6/N4: Q49.3 (C); also elsewhere on the board
/nixiedrivers6/N5: Q55.3 (C); also elsewhere on the board
/nixiedrivers6/N6: Q50.3 (C); also elsewhere on the board
/nixiedrivers6/N7: Q56.3 (C); also elsewhere on the board
/nixiedrivers6/N8: Q51.3 (C); also elsewhere on the board
/nixiedrivers6/N9: Q57.3 (C); also elsewhere on the board
/nixiedrivers6/NL: R73.1; also elsewhere on the board
GND: C21.2, C24.2, C27.2, C30.2, C33.2, Q14.2 (E), Q15.2 (E), Q16.2 (E), Q17.2 (E), Q18.2 (E), Q19.2 (E), Q20.2 (E), Q21.2 (E), Q22.2 (E), Q23.2 (E), Q24.2 (E), Q25.2 (E), Q26.2 (E), Q27.2 (E), Q28.2 (E), Q29.2 (E), Q30.2 (E), Q31.2 (E), Q32.2 (E), Q33.2 (E), Q34.2 (E), Q35.2 (E), Q36.2 (E), Q37.2 (E), Q38.2 (E), Q39.2 (E), Q40.2 (E), Q41.2 (E), Q42.2 (E), Q43.2 (E), Q44.2 (E), Q45.2 (E), Q46.2 (E), Q47.2 (E), Q48.2 (E), Q49.2 (E), Q50.2 (E), Q51.2 (E), Q52.2 (E), Q53.2 (E), Q54.2 (E), Q55.2 (E), Q56.2 (E), Q57.2 (E), Q58.2 (E), Q59.2 (E), Q60.2 (E), Q61.2 (E), Q62.2 (E), Q63.2 (E), Q64.2 (E), Q65.2 (E), Q66.2 (E), Q67.2 (E), Q68.2 (E), U15.12 (Vss), U15.23 (~EN), U16.12 (Vss), U16.23 (~EN), U17.12 (Vss), U17.23 (~EN), U18.12 (Vss), U18.23 (~EN), U19.12 (Vss), U19.23 (~EN); also elsewhere on the board
unnamed: Q14.1 (B), R28.1
unnamed: Q15.1 (B), R29.1
unnamed: Q16.1 (B), R30.1
unnamed: Q17.1 (B), R31.1
unnamed: Q18.1 (B), R32.1
unnamed: Q19.1 (B), R33.1
unnamed: Q19.3 (C), R34.2
unnamed: Q20.1 (B), R35.1
unnamed: Q21.1 (B), R36.1
unnamed: Q22.1 (B), R37.1
unnamed: Q23.1 (B), R38.1
unnamed: Q24.1 (B), R39.1
unnamed: Q25.1 (B), R41.1
unnamed: Q26.1 (B), R42.1
unnamed: Q27.1 (B), R43.1
unnamed: Q28.1 (B), R44.1
unnamed: Q29.1 (B), R45.1
unnamed: Q30.1 (B), R46.1
unnamed: Q30.3 (C), R47.2
unnamed: Q31.1 (B), R48.1
unnamed: Q32.1 (B), R49.1
unnamed: Q33.1 (B), R50.1
unnamed: Q34.1 (B), R51.1
unnamed: Q35.1 (B), R52.1
unnamed: Q36.1 (B), R54.1
unnamed: Q37.1 (B), R55.1
unnamed: Q38.1 (B), R56.1
unnamed: Q39.1 (B), R57.1
unnamed: Q40.1 (B), R58.1
unnamed: Q41.1 (B), R59.1
unnamed: Q41.3 (C), R60.2
unnamed: Q42.1 (B), R61.1
unnamed: Q43.1 (B), R62.1
unnamed: Q44.1 (B), R63.1
unnamed: Q45.1 (B), R64.1
unnamed: Q46.1 (B), R65.1
unnamed: Q47.1 (B), R67.1
unnamed: Q48.1 (B), R68.1
unnamed: Q49.1 (B), R69.1
unnamed: Q50.1 (B), R70.1
unnamed: Q51.1 (B), R71.1
unnamed: Q52.1 (B), R72.1
unnamed: Q52.3 (C), R73.2
unnamed: Q53.1 (B), R74.1
unnamed: Q54.1 (B), R75.1
unnamed: Q55.1 (B), R76.1
unnamed: Q56.1 (B), R77.1
unnamed: Q57.1 (B), R78.1
unnamed: Q58.1 (B), R80.1
unnamed: Q59.1 (B), R81.1
unnamed: Q60.1 (B), R82.1
unnamed: Q61.1 (B), R83.1
unnamed: Q62.1 (B), R84.1
unnamed: Q63.1 (B), R85.1
unnamed: Q63.3 (C), R86.2
unnamed: Q64.1 (B), R87.1
unnamed: Q65.1 (B), R88.1
unnamed: Q66.1 (B), R89.1
unnamed: Q67.1 (B), R90.1
unnamed: Q68.1 (B), R91.1
unnamed: R28.2, U15.11 (Q0)
unnamed: R29.2, U15.10 (Q2)
unnamed: R30.2, U15.7 (Q4)
unnamed: R31.2, U15.5 (Q6)
unnamed: R32.2, U15.18 (Q8)
unnamed: R35.2, U15.9 (Q1)
unnamed: R36.2, U15.8 (Q3)
unnamed: R37.2, U15.6 (Q5)
unnamed: R38.2, U15.4 (Q7)
unnamed: R39.2, U15.17 (Q9)
unnamed: R41.2, U16.11 (Q0)
unnamed: R42.2, U16.10 (Q2)
unnamed: R43.2, U16.7 (Q4)
unnamed: R44.2, U16.5 (Q6)
unnamed: R45.2, U16.18 (Q8)
unnamed: R48.2, U16.9 (Q1)
unnamed: R49.2, U16.8 (Q3)
unnamed: R50.2, U16.6 (Q5)
unnamed: R51.2, U16.4 (Q7)
unnamed: R52.2, U16.17 (Q9)
unnamed: R54.2, U17.11 (Q0)
unnamed: R55.2, U17.10 (Q2)
unnamed: R56.2, U17.7 (Q4)
unnamed: R57.2, U17.5 (Q6)
unnamed: R58.2, U17.18 (Q8)
unnamed: R61.2, U17.9 (Q1)
unnamed: R62.2, U17.8 (Q3)
unnamed: R63.2, U17.6 (Q5)
unnamed: R64.2, U17.4 (Q7)
unnamed: R65.2, U17.17 (Q9)
unnamed: R67.2, U18.11 (Q0)
unnamed: R68.2, U18.10 (Q2)
unnamed: R69.2, U18.7 (Q4)
unnamed: R70.2, U18.5 (Q6)
unnamed: R71.2, U18.18 (Q8)
unnamed: R74.2, U18.9 (Q1)
unnamed: R75.2, U18.8 (Q3)
unnamed: R76.2, U18.6 (Q5)
unnamed: R77.2, U18.4 (Q7)
unnamed: R78.2, U18.17 (Q9)
unnamed: R80.2, U19.11 (Q0)
unnamed: R81.2, U19.10 (Q2)
unnamed: R82.2, U19.7 (Q4)
unnamed: R83.2, U19.5 (Q6)
unnamed: R84.2, U19.18 (Q8)
unnamed: R87.2, U19.9 (Q1)
unnamed: R88.2, U19.8 (Q3)
unnamed: R89.2, U19.6 (Q5)
unnamed: R90.2, U19.4 (Q7)
unnamed: R91.2, U19.17 (Q9)
VCC: C21.1, C24.1, C27.1, C30.1, C33.1, U15.1 (EL), U15.24 (Vdd), U16.1 (EL), U16.24 (Vdd), U17.1 (EL), U17.24 (Vdd), U18.1 (EL), U18.24 (Vdd), U19.1 (EL), U19.24 (Vdd); also elsewhere on the board

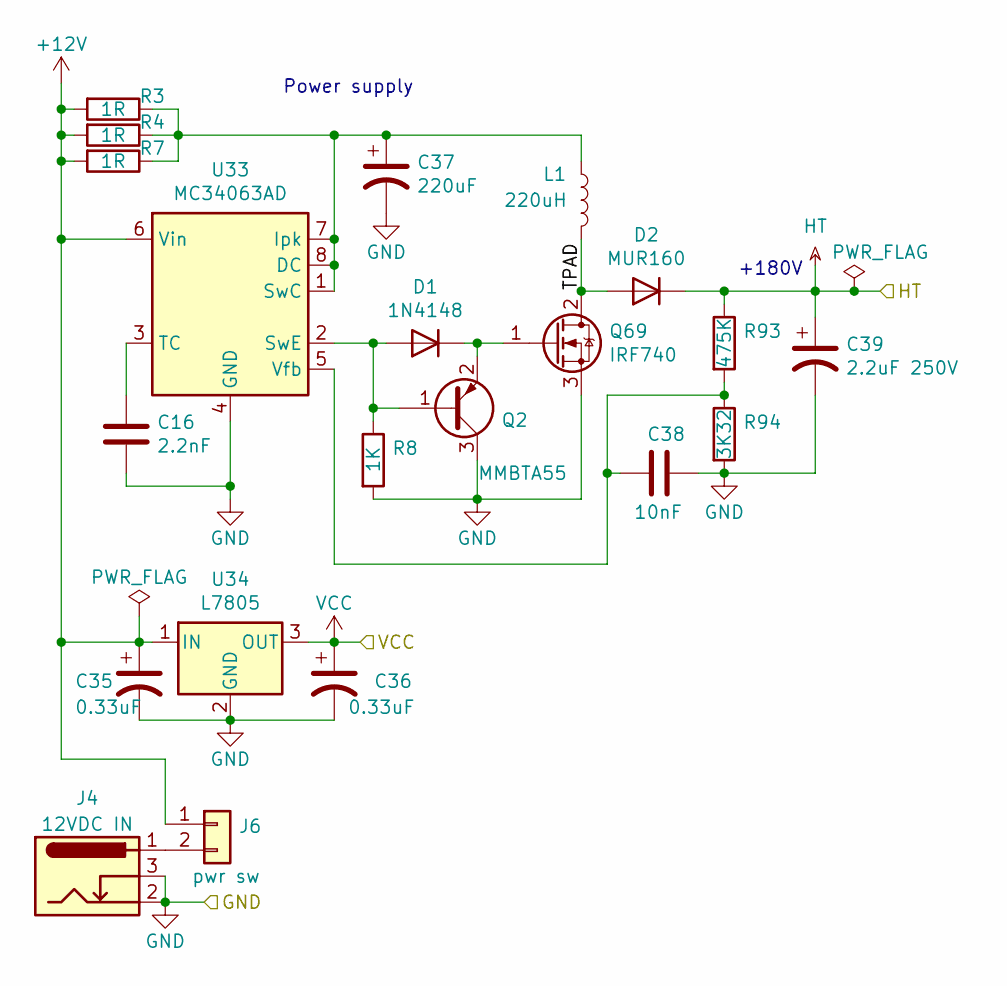
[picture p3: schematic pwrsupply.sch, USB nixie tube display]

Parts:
C16: 2.2nF; C_0805_2012Metric_Pad1.15x1.40mm_HandSolder
C35, C36: 0.33uF; CP_Elec_4x5.4
C37: 220uF; CP_Elec_8x10
C38: 10nF; C_0805_2012Metric_Pad1.15x1.40mm_HandSolder
C39: 2.2uF 250V; CP_Radial_D6.3mm_P2.50mm_Horizontal
D1: 1N4148; D_0805_2012Metric_Pad1.15x1.40mm_HandSolder
D2: MUR160; D_SMA-SMB_Universal_Handsoldering
J4: 12VDC IN; BarrelJack_Horizontal
J6: pwr sw; PinHeader_1x02_P2.54mm_Vertical
L1: 220uH; L_Bourns_SDR1806
Q2: MMBTA55; SOT-23
Q69: IRF740; TO-263-2
R3, R4, R7: 1R; R_0805_2012Metric_Pad1.15x1.40mm_HandSolder
R8: 1K; R_0805_2012Metric_Pad1.15x1.40mm_HandSolder
R93: 475K; R_0805_2012Metric_Pad1.15x1.40mm_HandSolder
R94: 3K32; R_0805_2012Metric_Pad1.15x1.40mm_HandSolder
U33: MC34063AD; SOIC-8_3.9x4.9mm_P1.27mm
U34: L7805; TO-252-2

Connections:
+12V: C35.1, J6.1, R3.2, R4.2, R7.2, U33.6 (Vin), U34.1 (IN)
/pwrsupply/TPAD: D2.2 (A), L1.2, Q69.2 (D)
GND: C16.2, C35.2, C36.2, C37.2, C38.1, C39.2, J4.2, J4.3, Q2.3 (C), Q69.3 (S), R8.2, R94.2, U33.4 (GND), U34.2 (GND); also elsewhere on the board
HT: C39.1, D2.1 (K), R93.1; also elsewhere on the board
unnamed: C16.1, U33.3 (TC)
unnamed: C37.1, L1.1, R3.1, R4.1, R7.1, U33.1 (SwC), U33.7 (Ipk), U33.8 (DC)
unnamed: C38.2, R93.2, R94.1, U33.5 (Vfb)
unnamed: D1.1 (K), Q2.2 (E), Q69.1 (G)
unnamed: D1.2 (A), Q2.1 (B), R8.1, U33.2 (SwE)
unnamed: J4.1, J6.2
VCC: C36.1, U34.3 (OUT); also elsewhere on the board

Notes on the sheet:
+180V
Power supply

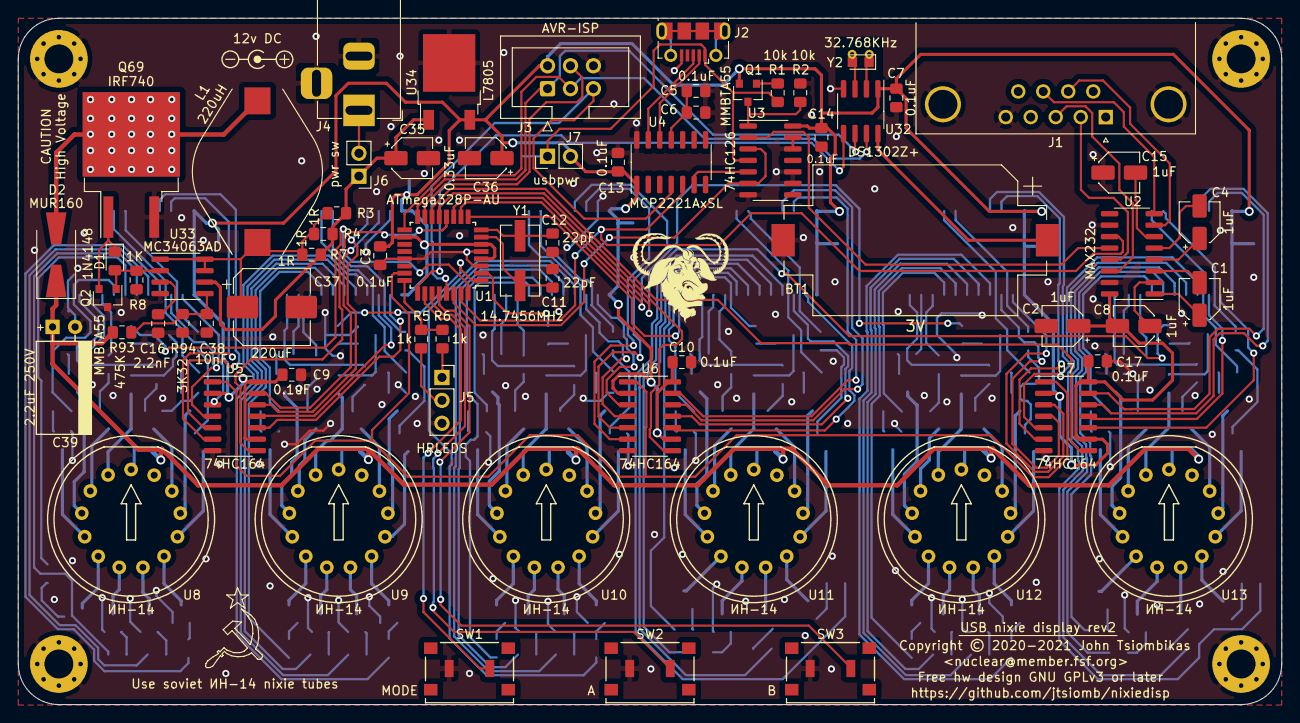
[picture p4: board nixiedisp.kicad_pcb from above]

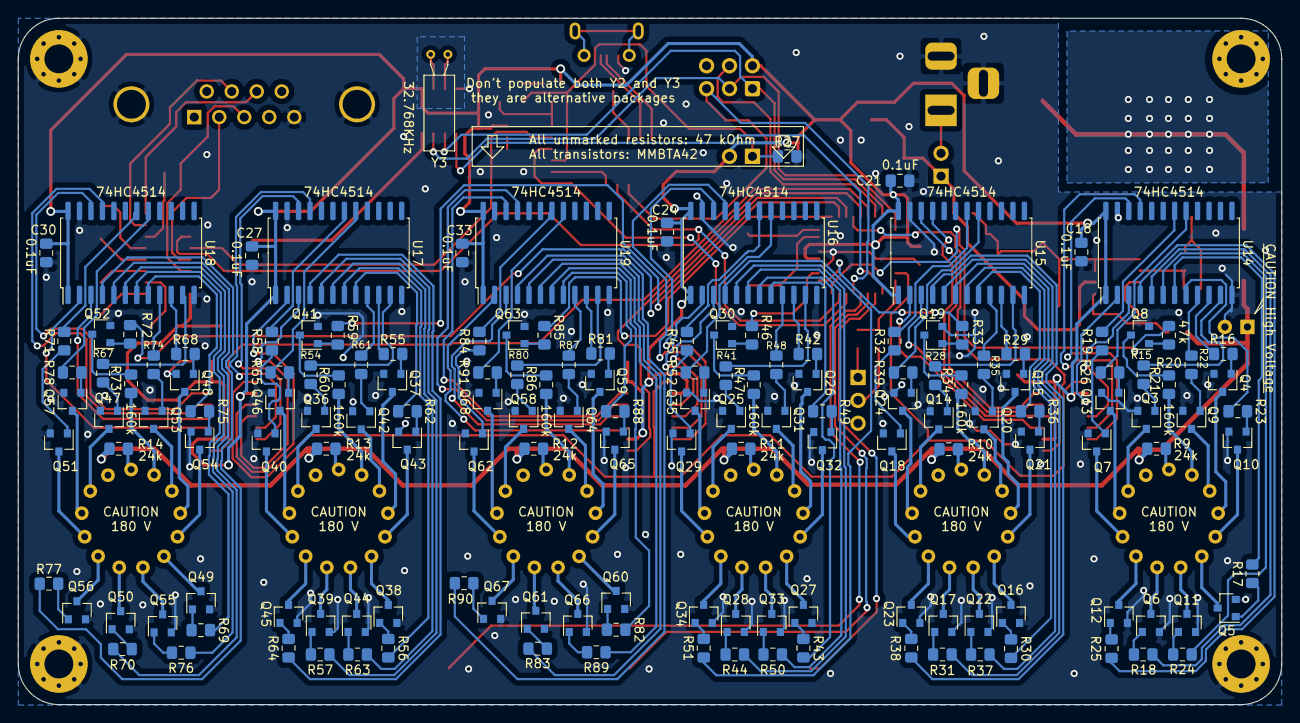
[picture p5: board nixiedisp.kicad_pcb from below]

Board: 2 copper layers, 140.0 x 76.1 mm, 229 parts (158 on the bottom side), 285 nets.

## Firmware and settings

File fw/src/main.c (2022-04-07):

#include <stdio.h>
#include <stdlib.h>
#include <stdint.h>
#include <string.h>
#include <ctype.h>
#include <avr/io.h>
#include <avr/interrupt.h>
#include <avr/power.h>
#include <util/delay.h>
#include <avr/pgmspace.h>
#include "serial.h"
#include "ds1302rtc.h"
#include "timer.h"
#include "config.h"

#define SRAM_MAGIC	"NIXIEDISP1"

#define SEP_LEVELS	64

#define FADE_TIME	1023
#define HALF_FADE	511
#define FADE_SHIFT	5

#define DEBOUNCE_ITER	32

static void handle_button(unsigned char bn);
static void proc_cmd(char *input);
static int switch_mode(int m);
static void setdigit(int idx, unsigned char val);
static void update_display(void);
static void cycle_disp(void);
static int boolarg(char *args, unsigned char *flags, unsigned char bit);
static int load_opt(void);
static void save_opt(void);
static void numchange(long delta);
static void read_buttons(void);

enum {
	OPT_CLK0	= 1,
	OPT_CLKSEC	= 2,
	OPT_CLK12	= 4
};

struct options {
	char magic[10];
	unsigned char level[6];
	unsigned char glevel, dot_level, sep_level;
	unsigned char fademask;
	unsigned char flags;
	unsigned char cycle_time[3];
};

static struct options def_opt = {
	SRAM_MAGIC,
	{15, 15, 15, 15, 15, 15},
	15, 15, SEP_LEVELS / 2,		/* glevel, dot_level, sep_level */
	0,				/* fademask */
	0x02,			/* flags: CLK0=0, CLKSEC=1, CLK12=0 */
	{6, 0, 0}		/* anti-cathode poisoning cycle schedule (6am) */
};
static struct options opt;

enum { MODE_CLOCK, MODE_TIMER, MODE_NUM };
static const char *modename[] = {"clock", "timer", "number"};

static int mode, timeset;
static unsigned char echo, blank;
static unsigned char disp[7], prev[6], fdisp[6];
static unsigned int fade_time[6];
static unsigned char dotmask;

static struct rtc_time tm;
static struct rtc_date date;

static unsigned int frame;
static int press_frm;

static char input[64];
static unsigned char inp_cidx;

static unsigned char bnstate, bnpress, bnprev, bndiff;


int main(void)
{
	/* SPI (SS/MOSI/SCK) are outputs */
	DDRB = ~PB_RTC_DATA;	/* port B all outputs except the RTC data line */
	PORTB = 0;
	DDRC = ~PC_BNMASK;		/* port C all outputs, except buttons */
	PORTC = PC_BNMASK;		/* enable button pullups */
	DDRD = 0xff;			/* port D all outputs */
	PORTD = 0;
#ifdef HAS_PORT_E
	DDRE = 0;	/* 328pb port E is where GND and VCC pins are in 328p, make them inputs */
	PORTE = 0;	/* also disable pullups */
#endif

	/* init the serial port we use to talk to the host */
	init_serial(38400);
	sei();

	rtc_init();
	timer_init();

	cycle_disp();

	if(load_opt() == -1) {
		opt = def_opt;
		save_opt();
	}

	for(;;) {
		if(have_input()) {
			int c = getchar();
			if(echo) {
				putchar(c);
			}

			if(c == '\r' || c == '\n') {
				if(echo) putchar('\n');
				input[inp_cidx] = 0;
				proc_cmd(input);
				inp_cidx = 0;
			} else if(inp_cidx < sizeof input - 1) {
				input[inp_cidx++] = c;
			}
		}

		read_buttons();

		if(timeset) {
			if(bnpress) {
				if(bnpress & PC_BN_MODE) {
					if(timeset++ >= 6) {
						timeset = 0;
						bnpress = 0;
						continue;
					}
				} else {
					handle_button(bnpress);
				}
			}

			if(timeset <= 3) {
				rtc_get_time_bcd(&tm);
			} else {
				rtc_get_date_bcd(&date);
			}

		} else {
			if(bnpress) {
				if(bnpress & PC_BN_MODE) {
					switch_mode((mode + 1) % 3);
				}

				if(bnpress & ~PC_BN_MODE) {	/* if other buttons changed state... */
					handle_button(bnpress & ~PC_BN_MODE);
				}
			}

			if(bnstate & PC_BN_A) {
				if(mode == MODE_CLOCK && frame - press_frm >= 10000) {
					timeset = 1;
				}
			}

			if(bnstate & PC_BN_B) {
				rtc_get_date_bcd(&date);
			} else {
				rtc_get_time_bcd(&tm);
			}

			if(tm.hour == opt.cycle_time[0] && tm.min == opt.cycle_time[1] && tm.sec == opt.cycle_time[2]) {
				cycle_disp();
			}
		}
		bnpress = 0;

		update_display();
	}
	return 0;
}

static void handle_button(unsigned char pressed)
{
	switch(mode) {
	case MODE_TIMER:
		if(pressed & PC_BN_A) {
			if(timer_running) {
				timer_stop();
			} else {
				timer_start();
			}
		}
		if(pressed & PC_BN_B) {
			timer_reset();
		}
		break;

	case MODE_NUM:
		if(pressed & PC_BN_A) {
			numchange(-1);
		}
		if(pressed & PC_BN_B) {
			numchange(1);
		}
		break;

	case MODE_CLOCK:
		if(timeset) {
			if(timeset <= 3) {
				rtc_get_time(&tm);
			} else {
				rtc_get_date(&date);
			}
			if(bnstate & PC_BN_B) {
				/* increment current field */
				switch(timeset) {
				case 1:
					if(++tm.hour >= 24) tm.hour = 0;
					rtc_set_time(tm.hour, tm.min, tm.sec);
					break;
				case 2:
					if(++tm.min >= 60) tm.min = 0;
					rtc_set_time(tm.hour, tm.min, tm.sec);
					break;
				case 3:
					rtc_set_time(tm.hour, tm.min, 0);
					break;
				case 4:
					if(++date.day > 31) date.day = 1;
					rtc_set_date(date.year, date.month, date.day);
					break;
				case 5:
					if(++date.month > 12) date.month = 1;
					rtc_set_date(date.year, date.month, date.day);
					break;
				case 6:
					rtc_set_date(++date.year, date.month, date.day);
				default:
					break;
				}

			} else if(bnstate & PC_BN_A) {
				/* decrement current field */
				switch(timeset) {
				case 1:
					if(--tm.hour < 0) tm.hour = 23;
					rtc_set_time(tm.hour, tm.min, tm.sec);
					break;
				case 2:
					if(--tm.min < 0) tm.min = 59;
					rtc_set_time(tm.hour, tm.min, tm.sec);
					break;
				case 3:
					rtc_set_time(tm.hour, tm.min, 0);
					break;
				case 4:
					if(--date.day < 1) date.day = 31;
					rtc_set_date(date.year, date.month, date.day);
					break;
				case 5:
					if(--date.month < 1) date.month = 12;
					rtc_set_date(date.year, date.month, date.day);
					break;
				case 6:
					if(date.year > 2000) {
						rtc_set_date(--date.year, date.month, date.day);
					}
				default:
					break;
				}
			}

		} else {
			if(pressed & PC_BN_A) {
				press_frm = frame;
			}
		}
		break;

	default:
		break;
	}
}


static const char helpstr[] __attribute__((progmem)) =
	"nixiedisp firmware v" VERSTR " by John Tsiombikas <nuclear@member.fsf.org>\n"
	"  web: http://nuclear.mutantstargoat.com/hw/nixiedisp\n"
	"  git: https://github.com/jtsiomb/nixiedisp\n"
	"\n"
	"Commands:\n"
	" <num>: set number\n"
	" e 0|1: echo\n"
	" b 0|1: blank display\n"
	" m n|c|t: mode (number/clock/timer)\n"
	" M 24|12: clock mode (24h/12h)\n"
	" z 0|1: clock leading zero\n"
	" S 0|1: clock seconds display\n"
	" s <hr>:<min>.<sec>: set clock\n"
	" d <day>/<mon>/<year>: set date\n"
	" L <level>: global intensity (0-15)\n"
	" H <level>: hour separator intensity (0-63)\n"
	" l <levels>: intensity (nibble per digit)\n"
	" x <mask>: fade mask (6 bits)\n"
	" t 0|1|r: timer stop/start/reset\n"
	" c: run anti-cathode poisoning cycle\n"
	" C <hr>:<min>.<sec>: set time to run cycle\n";

static void proc_cmd(char *input)
{
	int i, cmd, hr, min, sec, day, mon, year;
	long tmp;
	char c;
	char *args, *endp;
	const char *str;

	while(*input && isspace(*input)) input++;
	if(!*input) return;

	cmd = *input;
	args = input + 1;
	while(*args && isspace(*args)) args++;

	switch(cmd) {
	case 'e':
		if(args[0] != '?') {
			if(boolarg(args, &echo, 1) == -1) break;
		}
		printf("OK echo %s\n", echo ? "on" : "off");
		break;

	case 'b':
		if(args[0] != '?') {
			if(boolarg(args, &blank, 1) == -1) break;
		}
		printf("OK blanking: %s\n", blank ? "on" : "off");
		break;

	case 'z':
		if(args[0] != '?') {
			if(boolarg(args, &opt.flags, OPT_CLK0) == -1) break;
			save_opt();
		}
		printf("OK clock leading zero %s\n", opt.flags & OPT_CLK0 ? "on" : "off");
		break;

	case 'S':
		if(args[0] != '?') {
			if(boolarg(args, &opt.flags, OPT_CLKSEC) == -1) break;
			save_opt();
		}
		printf("OK seconds display %s\n", opt.flags & OPT_CLKSEC ? "on" : "off");
		break;

	case 'm':
		if(args[0] == '?') {
			printf("OK current mode: %s\n", modename[mode]);
			break;
		}
		if(switch_mode(args[0]) == -1) {
			printf("ERR invalid mode: '%s'\n", args);
			break;
		}
		printf("OK %s mode\n", modename[mode]);
		break;

	case 'M':
		if(args[0] != '?') {
			if(args[0] == '1' && args[1] == '2') {
				opt.flags |= OPT_CLK12;
			} else if(args[0] == '2' && args[1] == '4') {
				opt.flags &= ~OPT_CLK12;
			} else {
				printf("ERR invalid clock mode: '%s'\n", args);
				break;
			}
			save_opt();
		}
		printf("OK clock mode: %shr\n", opt.flags & OPT_CLK12 ? "12" : "24");
		break;

	case 's':
		if(args[0] == '?') {
			struct rtc_time tm;
			rtc_get_time(&tm);
			printf("OK current time: %02d:%02d.%02d\n", tm.hour, tm.min, tm.sec);
			break;
		}
		sec = 0;
		if(sscanf(args, "%d:%d.%d", &hr, &min, &sec) < 2 || hr < 0 || hr >= 24 ||
				min < 0 || min >= 60 || sec < 0 || sec >= 60) {
			printf("ERR invalid time string: \"%s\"\n", args);
			break;
		}
		rtc_set_time(hr, min, sec);
		printf("OK clock set %02d:%02d.%02d\n", hr, min, sec);
		break;

	case 'C':
		if(args[0] == '?') {
			printf("OK cycle time: %02d:%02d.%02d\n",
					(int)opt.cycle_time[0], (int)opt.cycle_time[1], (int)opt.cycle_time[2]);
			break;
		}
		sec = 0;
		if(sscanf(args, "%d:%d.%d", &hr, &min, &sec) < 2 || hr < 0 || hr >= 24 ||
				min < 0 || min >= 60 || sec < 0 || sec >= 60) {
			printf("ERR invalid time string: \"%s\"\n", args);
			break;
		}
		opt.cycle_time[0] = rtc_bin2bcd(hr);
		opt.cycle_time[1] = rtc_bin2bcd(min);
		opt.cycle_time[2] = rtc_bin2bcd(sec);
		printf("OK cycle scheduled for %02d:%02d.%02d\n", hr, min, sec);
		save_opt();
		break;

	case 'd':
		if(args[0] == '?') {
			struct rtc_date date;
			rtc_get_date(&date);
			printf("OK current date: %d/%d/%d\n", date.day, date.month, date.year);
			break;
		}
		if(sscanf(args, "%d/%d/%d", &day, &mon, &year) != 3 || day < 1 || day > 31 ||
				mon < 1 || mon > 12 || year < 0) {
			printf("ERR invalid date string: \"%s\"\n", args);
			break;
		}
		if(year < 100) year += 2000;
		rtc_set_date(year, mon, day);
		printf("OK date set to %d/%d/%d\n", day, mon, year);
		break;

	case 'L':
		if(args[0] != '?') {
			tmp = strtol(args, &endp, 10);
			if(endp == args || tmp < 0 || tmp > 15) {
				printf("ERR invalid intensity level: \"%s\"\n", args);
				break;
			}
			opt.glevel = tmp;
			save_opt();
		}
		printf("OK %d\n", opt.glevel);
		break;

	case 'H':
		if(args[0] != '?') {
			tmp = strtol(args, &endp, 10);
			if(endp == args || tmp < 0 || tmp >= SEP_LEVELS) {
				printf("ERR invalid hour separator intensity: \"%s\"\n", args);
				break;
			}
			opt.sep_level = tmp;
			save_opt();
		}
		printf("OK %d\n", opt.sep_level);
		break;

	case 'l':
		if(args[0] != '?') {
			tmp = strtol(args, &endp, 0);
			if(endp == args || (tmp & 0xff000000)) {
				printf("ERR invalid intensity string: \"%s\"\n", args);
				break;
			}
			for(i=0; i<6; i++) {
				opt.level[i] = (tmp >> 20) & 0xf;
				tmp <<= 4;
			}
			save_opt();
		}
		printf("OK");
		for(i=0; i<6; i++) {
			printf(" %d", (unsigned int)opt.level[i]);
		}
		putchar('\n');
		break;

	case 'x':
		if(args[0] != '?') {
			tmp = strtol(args, &endp, 0);
			if(endp == args) {
				printf("ERR invalid fade mask: \"%s\"\n", args);
				break;
			}
			opt.fademask = tmp;
			save_opt();
		}
		printf("OK fade mask: %02x\n", opt.fademask);
		break;

	case 't':
		if(args[0] == '?') {
			printf("OK timer %s: %lu\n", timer_running ? "running" : "stopped", nticks);
			break;
		}
		if(args[0] == '0') {
			timer_stop();
			printf("OK timer stopped\n");
		} else if(args[0] == '1') {
			timer_start();
			printf("OK timer started\n");
		} else if(args[0] == 'r') {
			timer_reset();
			printf("OK timer reset\n");
		} else {
			printf("ERR invalid timer command: \"%s\"\n", args);
		}
		break;

	case 'c':
		printf("OK cycling display\n");
		cycle_disp();
		break;

	case 'R':
		printf("OK resetting options\n");
		opt = def_opt;
		save_opt();
		break;

	case '>':
		if(mode == MODE_NUM) {
			tmp = atoi(args);
			numchange(tmp > 0 ? tmp : 1);
		}
		break;

	case '<':
		if(mode == MODE_NUM) {
			tmp = atoi(args);
			numchange(-(tmp > 0 ? tmp : 1));
		}
		break;

	case '?':
	case 'h':
		puts("OK command help");
		str = helpstr;
		while((c = pgm_read_byte(str++))) {
			putchar(c);
		}
		break;

	default:
		if(isdigit(cmd) || cmd == '.') {
			int c, didx;
			char *end;

			end = input;
			while(*end && (isdigit(*end) || *end == '.' || *end == ' ')) end++;
			if(end == input) break;

			dotmask = 0;
			didx = 5;
			while(end > input && didx >= 0) {
				c = *--end;
				if(c == '.') {
					dotmask |= 1 << (didx + 1);
				} else if(c == ' ') {
					setdigit(didx--, 0xff);
				} else {
					setdigit(didx--, c - '0');
				}
			}

			if(end > input && *--end == '.') {
				dotmask |= 1;
			}

			/* fill the leading digits with 0xff, which means blank */
			while(didx >= 0) {
				disp[didx--] = 0xff;
			}

		} else {
			printf("ERR unknown command: '%c'\n", cmd);
		}
	}
}

static int switch_mode(int m)
{
	switch(m) {
	case 'c':
		m = MODE_CLOCK;
		break;
	case 'n':
		m = MODE_NUM;
		break;
	case 't':
		m = MODE_TIMER;
		break;
	}

	if(m == mode) return 0;

	switch(m) {
	case MODE_CLOCK:
		break;

	case MODE_NUM:
		PORTC &= ~PC_HRSEP;
		disp[0] = disp[1] = disp[2] = disp[3] = disp[4] = disp[5] = 0xff;
		dotmask = 0;
		break;

	case MODE_TIMER:
		PORTC &= ~PC_HRSEP;
		dotmask = 0;
		break;

	default:
		return -1;
	}

	mode = m;
	return 0;
}

static void setdigit(int idx, unsigned char val)
{
	unsigned char *dptr = disp + idx;

	if(val == *dptr) return;

	prev[idx] = *dptr;
	*dptr = val;
	fade_time[idx] = FADE_TIME;
}

static void shiftout(int sreg, unsigned char val)
{
	int i;
	unsigned int clkbit = 1 << sreg;

	for(i=0; i<8; i++) {
		PORTC = (PORTC & 0xfe) | (val >> 7);
		PORTB = (PORTB & 0xf8) | clkbit;
		PORTB &= 0xf8;
		val <<= 1;
	}
}

static unsigned char c12lut[] = {
	0x12, 1, 2, 3, 4, 5, 6, 7, 8, 9, 0xff, 0xff, 0xff, 0xff, 0xff, 0xff,
	0x10, 0x11, 0x12, 1, 2, 3, 4, 5, 6, 7, 0xff, 0xff, 0xff, 0xff, 0xff, 0xff,
	8, 9, 0x10, 0x11, 0x12
};

static void update_display(void)
{
	int i, hour, sec, mplex, lvl, dframe, fade, fadeout, dp = 0;
	unsigned char *dptr, digit;
	unsigned long tval;

	/* mplex is used to multiplex the decimal point 1/4 of the time with the
	 * digits the rest 3/4. if we ignite both the decimal point and a digit in
	 * the same tube, it leads to a fuzzy glow around the decimal point
	 */
	mplex = ++frame & 3;

	if(blank) {
		shiftout(0, 0xff);
		shiftout(1, 0xff);
		shiftout(2, 0xff);
		PORTC &= ~PC_HRSEP;
		PORTD = 0;
		return;
	}


	switch(mode) {
	case MODE_CLOCK:
		if((!timeset && (bnstate & PC_BN_B)) || timeset > 3) {
			/* show date while holding down B */
			setdigit(0, date.day & 0xf0 ? date.day >> 4 : 0xff);
			setdigit(1, date.day & 0xf);
			setdigit(2, date.month & 0xf0 ? date.month >> 4 : 0xff);
			setdigit(3, date.month & 0xf);
			setdigit(4, date.year >> 4);
			setdigit(5, date.year & 0xf);
			dp = 0x14;
			PORTC &= ~PC_HRSEP;
		} else {
			/* otherwise show the time */
			hour = (opt.flags & OPT_CLK12) ? c12lut[tm.hour] : tm.hour;

			setdigit(0, (opt.flags & OPT_CLK0) || (hour & 0xf0) ? hour >> 4 : 0xf);
			setdigit(1, hour & 0xf);
			setdigit(2, tm.min >> 4);
			setdigit(3, tm.min & 0xf);
			if(opt.flags & OPT_CLKSEC) {
				setdigit(4, tm.sec >> 4);
				setdigit(5, tm.sec & 0xf);

				/* dot is always in the seconds tube when in clock mode */
				dp = 0x10;
			} else {
				setdigit(4, 0xf);
				setdigit(5, 0xf);

				dp = 0;
			}

			if((frame & (SEP_LEVELS - 1)) <= opt.sep_level) {
				PORTC |= PC_HRSEP;
			} else {
				PORTC &= ~PC_HRSEP;
			}
		}
		break;

	case MODE_TIMER:
		tval = nticks / 10;

		setdigit(5, tval % 10);
		tval /= 10;
		setdigit(4, tval % 10);
		tval /= 10;

		sec = tval % 60;
		tval /= 60;

		setdigit(3, sec % 10);
		sec /= 10;
		setdigit(2, sec % 10);

		setdigit(1, tval % 10);
		tval /= 10;
		setdigit(0, tval % 10);

		dp = 0x14;	/* dots on both the seconds (2) and hundredths (4) tube */
		break;

	case MODE_NUM:
	default:
		dp = dotmask;
	}


	/* handle dimming by splitting a display cycle into 16 sections, and
	 * keeping the tube off for a fraction of those, even if it's supposed
	 * to display a digit.
	 */
	dframe = frame & 0xf;

	if(!dp || mplex) {
		/* dot is not visible at all, or it is, but we're in the 3/4 of the time
		 * when we display digits
		 */

		if(timeset) {
			/* if we're setting the time, dim the non-active digits */
			for(i=0; i<3; i++) {
				if(i == timeset - 1 || i == timeset - 4) {
					fdisp[i * 2] = disp[i * 2];
					fdisp[i * 2 + 1] = disp[i * 2 + 1];
				} else {
					fdisp[i * 2] = dframe < 4 ? disp[i * 2] : 0xff;
					fdisp[i * 2 + 1] = dframe < 4 ? disp[i * 2 + 1] : 0xff;
				}
			}

		} else {
			/* normal operation */

			for(i=0; i<6; i++) {
				lvl = opt.glevel * opt.level[i] >> 4;

				if((opt.fademask & (0x20 >> i)) && fade_time[i]) {
					fadeout = fade_time[i] > HALF_FADE ? 1 : 0;
					fade = fadeout ? fade_time[i] - HALF_FADE : HALF_FADE - fade_time[i];
					digit = fadeout ? prev[i] : disp[i];

					lvl = lvl * (fade >> FADE_SHIFT) >> 4;

					fdisp[i] = dframe <= lvl ? digit : 0xff;
				} else {
					fdisp[i] = dframe <= lvl ? disp[i] : 0xff;
				}

				if(fade_time[i]) fade_time[i]--;
			}
		}
	} else {
		fdisp[0] = fdisp[1] = fdisp[2] = fdisp[3] = fdisp[4] = fdisp[5] = 0xff;
	}

	lvl = opt.glevel * opt.level[6] >> 4;
	if(!mplex && dp && dframe <= lvl) {
		/* dot is visible and we're in the 1/4 of the time when we display the dot */
		PORTD = dp << 2;	/* starts from pin 2 of the output port */
	} else {
		PORTD = 0;
	}

	dptr = fdisp;
	for(i=0; i<3; i++) {
		shiftout(i, (dptr[0] & 0xf) | (dptr[1] << 4));
		dptr += 2;
	}
}

static void cycle_disp(void)
{
	int i, j;

	PORTC &= ~PC_HRSEP;
	PORTD = 0;

	for(i=0; i<10; i++) {
		for(j=0; j<3; j++) {
			shiftout(j, i | (i << 4));
		}
		_delay_ms(120);
	}

	shiftout(0, 0xff);
	shiftout(1, 0xff);
	shiftout(2, 0xff);

	PORTD = 0xff;
	_delay_ms(140);
	PORTD = 0;

	for(i=0; i<10; i++) {
		int x = 9 - i;
		for(j=0; j<3; j++) {
			shiftout(j, x | (x << 4));
		}
		_delay_ms(120);
	}
}

static int boolarg(char *args, unsigned char *flags, unsigned char bit)
{
	if(!isdigit(args[0])) {
		printf("ERR invalid boolean value \"%s\", expecting 0 or 1\n", args);
		return -1;
	}

	if(*args == '0') {
		*flags &= ~bit;
	} else {
		*flags |= bit;
	}
	return 0;
}

static int load_opt(void)
{
	int i;
	unsigned char *ptr = (unsigned char*)&opt;

	for(i=0; i<sizeof opt; i++) {
		*ptr++ = rtc_load(i);
	}
	return memcmp(opt.magic, SRAM_MAGIC, sizeof opt.magic) == 0 ? 0 : -1;
}

static void save_opt(void)
{
	int i;
	unsigned char *ptr = (unsigned char*)&opt;

	for(i=0; i<sizeof opt; i++) {
		rtc_store(i, *ptr++);
	}
}

static void numchange(long delta)
{
	int i;
	unsigned long num, scale = 1;
	unsigned char *dptr = disp + 5;

	num = 0;
	for(i=0; i<6; i++) {
		if(*dptr <= 9) num += (unsigned long)*dptr * scale;
		dptr--;
		scale *= 10;
	}

	num += delta;

	for(i=0; i<6; i++) {
		setdigit(5 - i, num || i == 0 ? num % 10 : 0xff);
		num /= 10;
	}
}

static void read_buttons(void)
{
	static unsigned char cur, prev;
	static int count;

	prev = cur;
	cur = ~PINC & PC_BNMASK;

	if(cur == prev) {
		count++;
	} else {
		count = 0;
	}

	if(count > DEBOUNCE_ITER) {
		bnprev = bnstate;
		bnstate = cur;
		bndiff = bnstate ^ bnprev;
		bnpress = bndiff & bnstate;
		count = 0;
	}
}

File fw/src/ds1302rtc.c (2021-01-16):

#include <stdio.h>
#include <avr/io.h>
#include <util/delay.h>
#include "ds1302rtc.h"
#include "config.h"

#define CLOCK(x) \
	do { if(x) PORTB |= PB_RTC_CK; else PORTB &= ~PB_RTC_CK; } while(0)
#define CE(x) \
	do { if(x) PORTC |= PC_RTC_EN; else PORTC &= ~PC_RTC_EN; } while(0)
#define SET_IO(x) \
	do { if(x) PORTB |= PB_RTC_DATA; else PORTB &= ~PB_RTC_DATA; } while(0)
#define GET_IO ((PINB & PB_RTC_DATA) ? 1 : 0)
#define DDR_IO(x) \
	do { if(x) DDRB |= PB_RTC_DATA; else DDRB &= ~PB_RTC_DATA; } while(0)

#define IN	0
#define OUT	1

#define SRAM_BASE		0xc0
#define CMD_RD_BIT		0x01

#define REG_SEC		0x80
#define REG_MIN		0x82
#define REG_HOUR	0x84
#define REG_DOM		0x86
#define REG_MONTH	0x88
#define REG_DOW		0x8a
#define REG_YEAR	0x8c
#define REG_WPROT	0x8e
#define REG_CHARGER	0x90

#define SEC_CLOCK_HALT	0x80
#define HOUR_12MODE_BIT	0x80
#define WPROT_BIT		0x80

static void write_reg(int reg, unsigned char byte);
static unsigned char read_reg(int reg);
static void send_byte(unsigned char byte);
static unsigned char recv_byte(void);

void rtc_init(void)
{
	unsigned char tmp;

	write_reg(REG_WPROT, 0);
	write_reg(REG_CHARGER, 0);

	tmp = read_reg(REG_SEC);
	write_reg(REG_SEC, tmp & ~SEC_CLOCK_HALT);

	tmp = read_reg(REG_HOUR);
	write_reg(REG_HOUR, tmp & ~HOUR_12MODE_BIT);
}

void rtc_set_time(int hour, int min, int sec)
{
	unsigned char hval, mval, sval;

	hval = (hour % 10) | ((hour / 10) << 4);
	mval = (min % 10) | ((min / 10) << 4);
	sval = (sec % 10) | ((sec / 10) << 4);

	write_reg(REG_WPROT, 0);

	write_reg(REG_SEC, sval);
	write_reg(REG_MIN, mval);
	write_reg(REG_HOUR, hval);

	write_reg(REG_WPROT, WPROT_BIT);
}

void rtc_get_time(struct rtc_time *tm)
{
	unsigned char hval, mval, sval;

	sval = read_reg(REG_SEC);
	mval = read_reg(REG_MIN);
	hval = read_reg(REG_HOUR);

	tm->hour = (hval & 0x0f) + (((hval >> 4) & 3) * 10);
	tm->min = (mval & 0x0f) + (((mval >> 4) & 7) * 10);
	tm->sec = (sval & 0x0f) + (((sval >> 4) & 7) * 10);
}

void rtc_get_time_bcd(struct rtc_time *tm)
{
	tm->sec = read_reg(REG_SEC);
	tm->min = read_reg(REG_MIN);
	tm->hour = read_reg(REG_HOUR);
}

void rtc_set_date(int year, int month, int day)
{
	unsigned char yval, mval, dval;

	year -= 2000;
	yval = (year % 10) | ((year / 10) << 4);
	mval = (month % 10) | ((month / 10) << 4);
	dval = (day % 10) | ((day / 10) << 4);

	write_reg(REG_WPROT, 0);

	write_reg(REG_YEAR, yval);
	write_reg(REG_MONTH, mval);
	write_reg(REG_DOM, dval);

	write_reg(REG_WPROT, WPROT_BIT);
}

void rtc_set_weekday(int dow)
{
	write_reg(REG_WPROT, 0);
	write_reg(REG_DOW, dow);
	write_reg(REG_WPROT, 1);
}

void rtc_get_date(struct rtc_date *date)
{
	unsigned char yval, mval, dval, wval;

	yval = read_reg(REG_YEAR);
	mval = read_reg(REG_MONTH);
	dval = read_reg(REG_DOM);
	wval = read_reg(REG_DOW);

	date->year = (yval & 0x0f) + ((yval >> 4) * 10) + 2000;
	date->month = (mval & 0x0f) + (((mval >> 4) & 1) * 10);
	date->day = (dval & 0x0f) + (((dval >> 4) & 3) * 10);
	date->dow = wval & 7;
}

void rtc_get_date_bcd(struct rtc_date *date)
{
	date->year = read_reg(REG_YEAR);
	date->month = read_reg(REG_MONTH);
	date->day = read_reg(REG_DOM);
}

void rtc_store(int addr, unsigned char byte)
{
	write_reg(SRAM_BASE | (addr << 1), byte);
}

unsigned char rtc_load(int addr)
{
	return read_reg(SRAM_BASE | (addr << 1));
}

#define DATA_CLK_DELAY asm volatile("nop\n\tnop\n\t")

static void write_reg(int reg, unsigned char byte)
{
	CLOCK(0);
	CE(0);

	CE(1);
	send_byte(reg);
	send_byte(byte);
	CE(0);
}

static unsigned char read_reg(int reg)
{
	unsigned char res = 0;
	reg |= CMD_RD_BIT;

	CLOCK(0);
	CE(0);

	CE(1);
	send_byte(reg);
	res = recv_byte();
	CE(0);
	return res;
}

static void send_byte(unsigned char byte)
{
	int i;

	DDR_IO(OUT);

	for(i=0; i<8; i++) {
		CLOCK(0);
		_delay_us(0.25);
		SET_IO(byte & 1);
		DATA_CLK_DELAY;
		CLOCK(1);
		_delay_us(0.25);
		byte >>= 1;
	}
}

static unsigned char recv_byte(void)
{
	int i;
	unsigned char val = 0;

	DDR_IO(IN);

	for(i=0; i<8; i++) {
		CLOCK(0);
		_delay_us(0.25);
		val = (val >> 1) | (GET_IO ? 0x80 : 0);
		CLOCK(1);
		_delay_us(0.25);
	}
	return val;
}

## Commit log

2020-12-26 PCB layout: nixie driver transistors and decoding pretty much final
    [nixiedisp.kicad_pcb]
2020-12-26 added RTC to the schematic
    [nixiedisp.kicad_pcb, nixiedisp.sch, nixiedrivers.sch]
2020-12-27 PCB layout almost done
    [nixiedisp.kicad_pcb, nixiedisp.sch]
2020-12-27 finished the PCB rev1
    [nixiedisp-B_Cu.gbr, nixiedisp-B_Mask.gbr, nixiedisp-B_Paste.gbr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]
2020-12-27 schematic info
    [nixiedisp.sch, nixiedrivers.sch]
2020-12-30 minor pcb adjustments
    [nixiedisp.kicad_pcb]
2021-01-03 started on the firmware, added BOM
    [bom.ods, nixiedisp.sch]
2021-01-08 number mode works, added dot multiplexing to avoid fuzzy dots, and to reduce the brightness of the dots
    [main.c]
2021-01-09 updated BOM with components that need to changed for rev2, added power supply reference in the readme
    [bom.ods]
2021-01-09 global brightness control, PWM and crossfading
2021-01-09 turn on hour sep. leds in clock mode, and keep the decimal point in the seconds tube
2021-01-10 - now almost every command followed by a '?' queries the current option instead of setting it. - added option for when to run the anti-cathode poisoning cycling
2021-01-11 saving and restoring options from battery backed SRAM
2021-01-15 - fixed mistakes in the schematic - updated the PCB for the fixes - in process of adding a proper serial port with a max232
    [nixiedisp.kicad_pcb, nixiedisp.sch, nixiedrivers.sch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]
2021-01-15 halved the hour separator brightness levels to 64, to avoid flicker. It used to update at 40hz which was clearly visible. Now it should update at 80hz.
    [main.c]
2021-01-16 implemented the timer mode
2021-01-16 - added button handling in firmware (untested) - holding down button B while in clock mode shows the date - pressing buttons A/B while in number mode increments/decrements the number - pressing butto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
    [ds1302rtc.c, main.c]
2021-01-16 dropped the interrupt because I was too lazy to hardware-debounce the buttons, now polling and counting stable states for debouncing
2021-01-19 lots of changes, redesigning most of the PCB
    [bom.ods, nixiedisp.kicad_pcb, nixiedisp.sch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]
2021-01-19 PCB rev2 layout in progress
    [bom.ods, nixiedisp.kicad_pcb, nixiedisp.sch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]
2021-01-22 - fw: added check in the build system, to make sure we don't exceed the data space of the microcontroller - fw: added missing help item
    [main.c]
2021-02-09 rev2 board
    [bom.ods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]
2021-02-15 - exported fresh gerbers - updated the readme
    [nixiedisp-B_Cu.gbr, nixiedisp-B_Mask.gbr, nixiedisp-B_Paste.gbr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]
2021-02-15 updated the BOM
    [bom.ods]
2021-02-15 added the BOM in csv format
    [bom.csv]
2021-02-16 GUI fixes, and start of the windows port
    [bom.csv, bom.ods]
2021-02-18 - changed firmware to be less verbose when changing brightness, to reduce display flicker while dragging sliders in the GUI - nixiedisp-gui: added "reset defaults" menu action
    [main.c]

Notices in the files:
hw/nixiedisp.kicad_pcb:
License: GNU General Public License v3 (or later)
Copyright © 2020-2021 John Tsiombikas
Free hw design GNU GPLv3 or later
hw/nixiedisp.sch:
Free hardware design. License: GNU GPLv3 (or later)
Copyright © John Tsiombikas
